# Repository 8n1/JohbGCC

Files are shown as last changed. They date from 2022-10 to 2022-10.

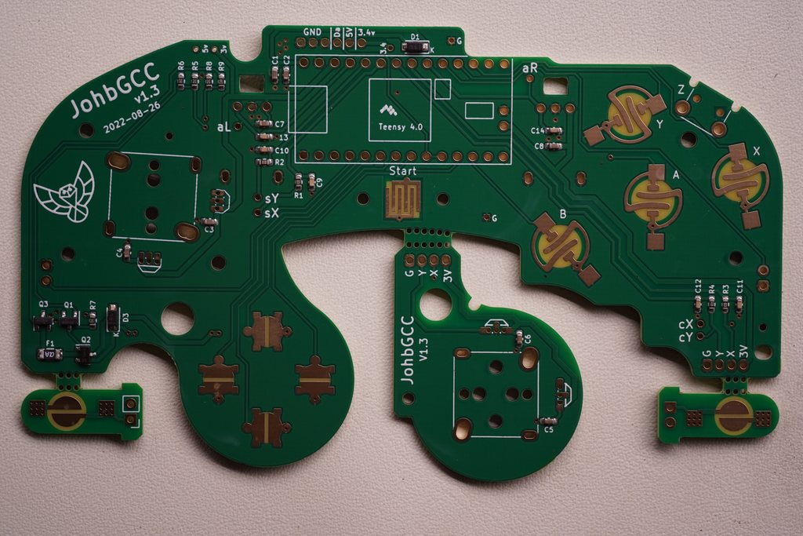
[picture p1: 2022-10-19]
Resources/johbgcc_board_top_v1_3.jpeg

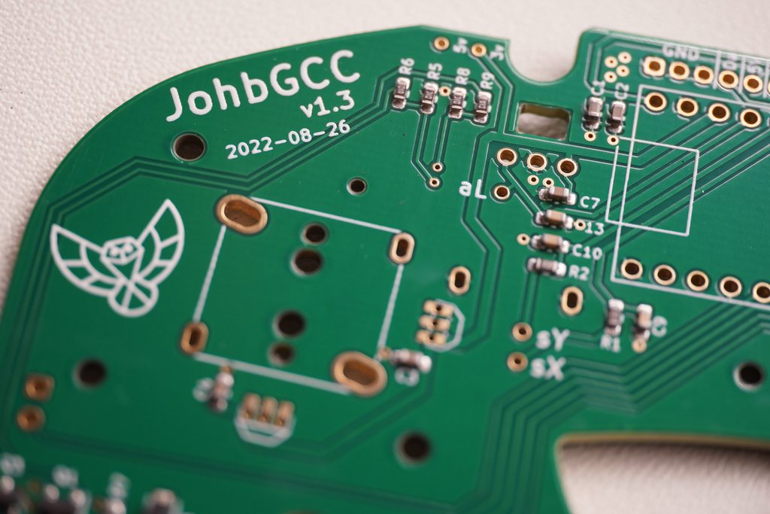
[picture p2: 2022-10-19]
Resources/johbgcc_board_v1_3.jpeg

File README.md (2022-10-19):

# JohbGCC v1.3


 
This board is based on the PhobGCC v1.2.3 board (https://github.com/PhobGCC/PhobGCC-HW).  
  
It is 100% compatible with the PhobGCC software but requires a custom teensy.h. (More info below).  

--- 
  
The Board was made with KiCad version 6.0.5.  
Gerber and assembly production files were created using the KiCad plugin "JLCPCB Tools"  (https://github.com/Bouni/kicad-jlcpcb-tools).  

# Changes

- **Rotated the stickbox into original position**  
- **Rotated the Teensy 180°**  
- **Optimized the board paneling for manufacturing**  
- **Added some labels to make it very fail proof and easier to build**  
- **Tried to make the board easier to desolder (More info below)**  

## Other changes 

- **Both hall sensors on the c stick have a decoupling capacitor now**  
- **Routed the 3.3V and filled the top layer with GND too**   

# PCB




# Schematic / PCB tracks

  
  
  
  

# Custom teensy.h
  
Before uploading the PhobGCC software to the Teensy you need to copy the teensy.h for this board ("Johb1_3Teensy4_0.h") into the "teensy" folder that comes with the Phob software and tell it to use it.   
  
The *teensy.h"* is the configuration file that tells the Phob software to what pins the buttons, triggers, hall sensors are connected to the Teensy.  
  
This board requires a custom one because I re-routed most of the board after rotating the Teensy and to keep tracks nice and short I switched the GPIO pins.  

## Adding the JohbGCC teensy.h 

**Step by step:**
1.  Download the PhobGCC software (https://github.com/PhobGCC/PhobGCC-SW/releases)
2.  Download the JohbGCC teensy.h (https://github.com/8n1/JohbGCC/blob/master/Johb1_3Teensy4_0.h) and put it into the "teensy" folder that is included in the PhobGCC software zip file.
3.  Edit the file "common/phobGCC.h" to use the added JohbGCC teensy.h by adding this line as shown in the picture below:  
```
#include "../teensy/Johb1_3Teensy4_0.h"             // For JohbGCC board 1.3.x with Teensy 4.0
```


4.  Done. Upload it to the Teensy. 

This has been tested with PhobGCC software v0.27 (https://github.com/PhobGCC/PhobGCC-SW/releases/tag/v0.27).  
For earlier versions the steps were slightly different.  
   
This is the only thing necessary to use the JohbGCC board with the PhobGCC software.  

# Modified/cut rumble bracket

It is necessary to modify the rumble bracket because the pins of the hall sensor interfere with it.  
  
**THIS MUST BE DONE, otherwise the controller can't be closed without force which causes various issues because the hall sensor pins will get crushed.**  
    
   
  
The text I put there says that it would be also possible to make the hall sensor pins flat instead but I found it much easier to just cut out a small part of the rumble bracket like shown in the pictures below so I would always recommend doing that.   
   
**"L" rumble bracket:**  
  
**Rumble bracket with integrated trigger guards:**  
  
More pictures before and after cutting:  
https://imgur.com/a/gytP62m  

# Making it easier to desolder

I wanted to make the holes for some parts like the L/R potentiometer and GCC cable not through hole plated to make it easier to desolder (as it is on a OEM GCC board) but I haven't looked into how to do this enough and misunderstood a option in KiCad ("connected layers only") so I didn't got exactly what I wanted:  
   
   
   
But that's not bad actually, part success!  
They are still through hole plated, what that option did was to only remove the solder ring on the side where it's not needed.

... 

After doing some research it looks like that KiCad doesn't has this exact option built in.   
But what you can do is take a smd pad and put a not trough hole plated hole (aka. mounting hole) in the middle of it. But this way this manufacturer specification limitation comes into play (this is from jlcpcb):  
   
  
(I want to try this out with the mounting pins of the potentiometers on the next board I make.)

# Pictures

**Hall sensor footprints on c stick**   
  
   
**Square indicators that show where the part/cable goes**   

  
**Labels that indicate hall sensor orientation**   


## More pictures

**Board as it came from JLCPCB:**  
https://imgur.com/a/ONnHoDy

**Soldered board:**  
https://imgur.com/a/rvYWUjU

***

# This project is based on PhobGCC
More informations about the PhobGCC project can be found here:  
https://github.com/PhobGCC  

***

# License
Text and images are licensed under Creative Commons CC-BY-SA.  
[Creative Commons Attribution-ShareAlike 4.0 International License](http://creativecommons.org/licenses/by-sa/4.0/ "Creative Commons Attribution-ShareAlike 4.0 International")  
  
  
KiCad board files are licensed under the CERN Open Hardware License.   
[CERN Open Hardware Licence Version 2 - Strongly Reciprocal](https://spdx.org/licenses/CERN-OHL-S-2.0.html "CERN Open Hardware Licence Version 2 - Strongly Reciprocal")  
Open source hardware logo  

***

If you have any questions contact me on discord (add me as a friend or find me in the PhobGCC discord): johgi#5103 (Might take a day or two to respond!)

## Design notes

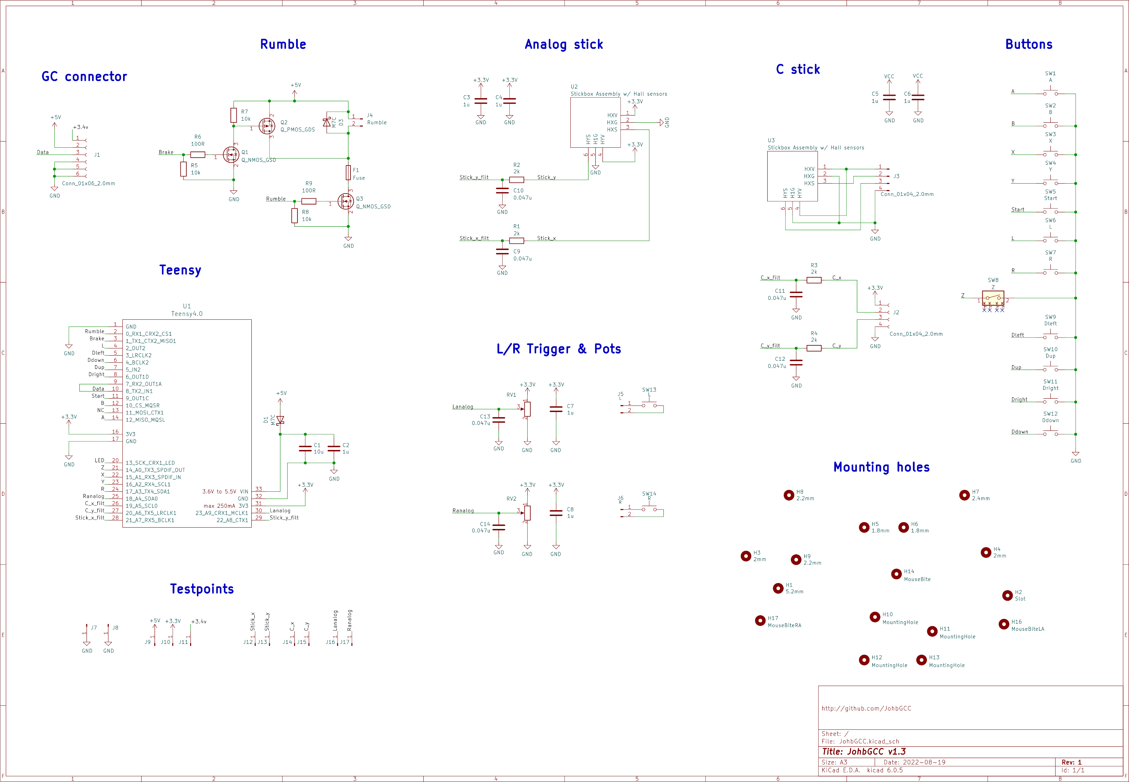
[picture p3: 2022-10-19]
Resources/johbgcc_schematic_v1_3.png

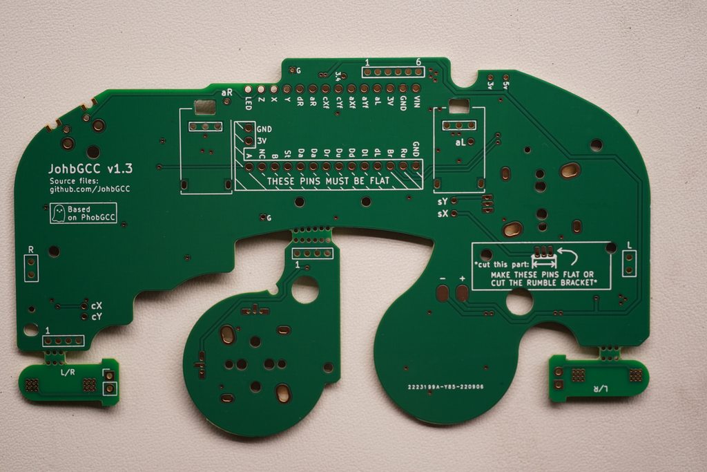
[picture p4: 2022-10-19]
Resources/johbgcc_board_bottom_v1_3.jpeg

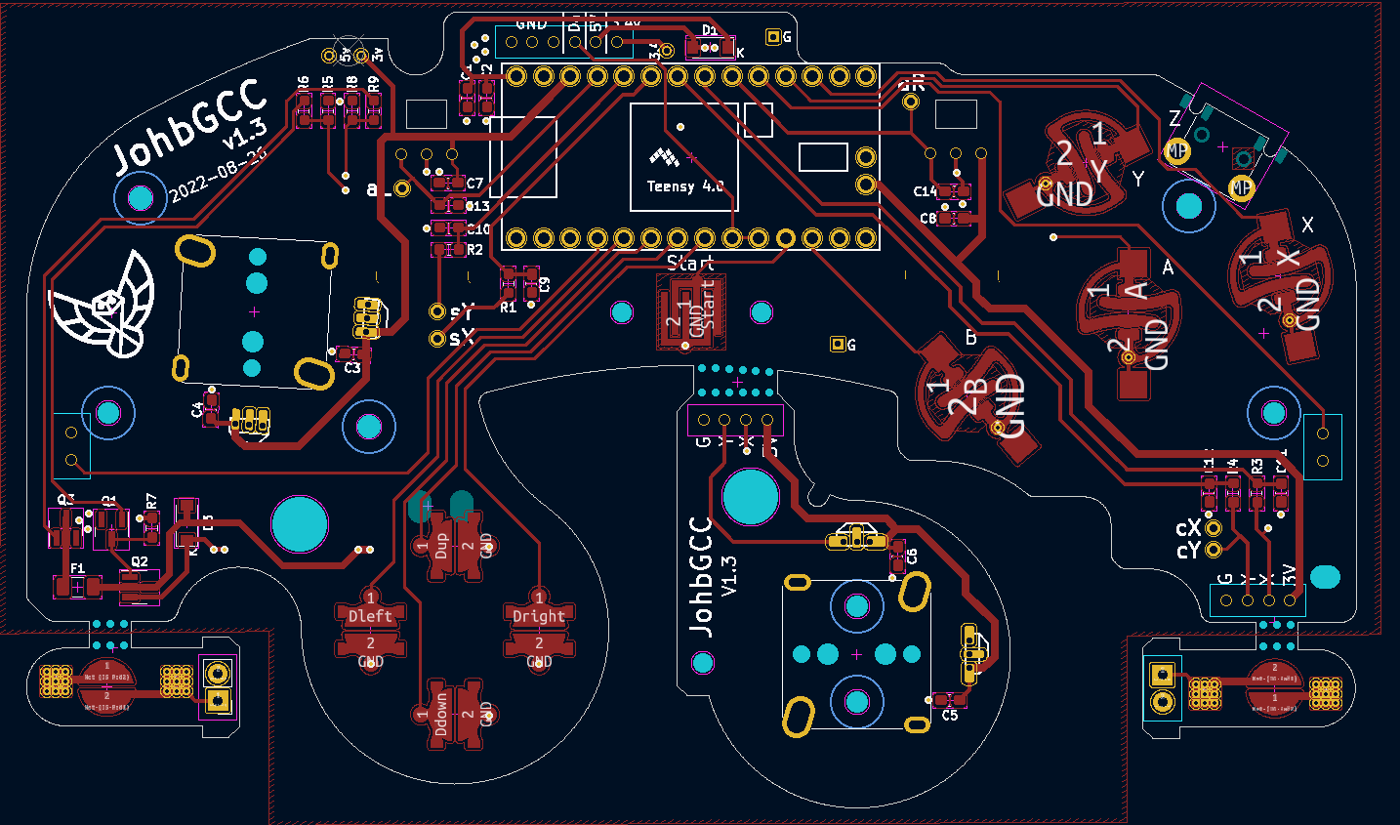
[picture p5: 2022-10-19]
Resources/johbgcc_pcb_tracks_top_v1_3.png

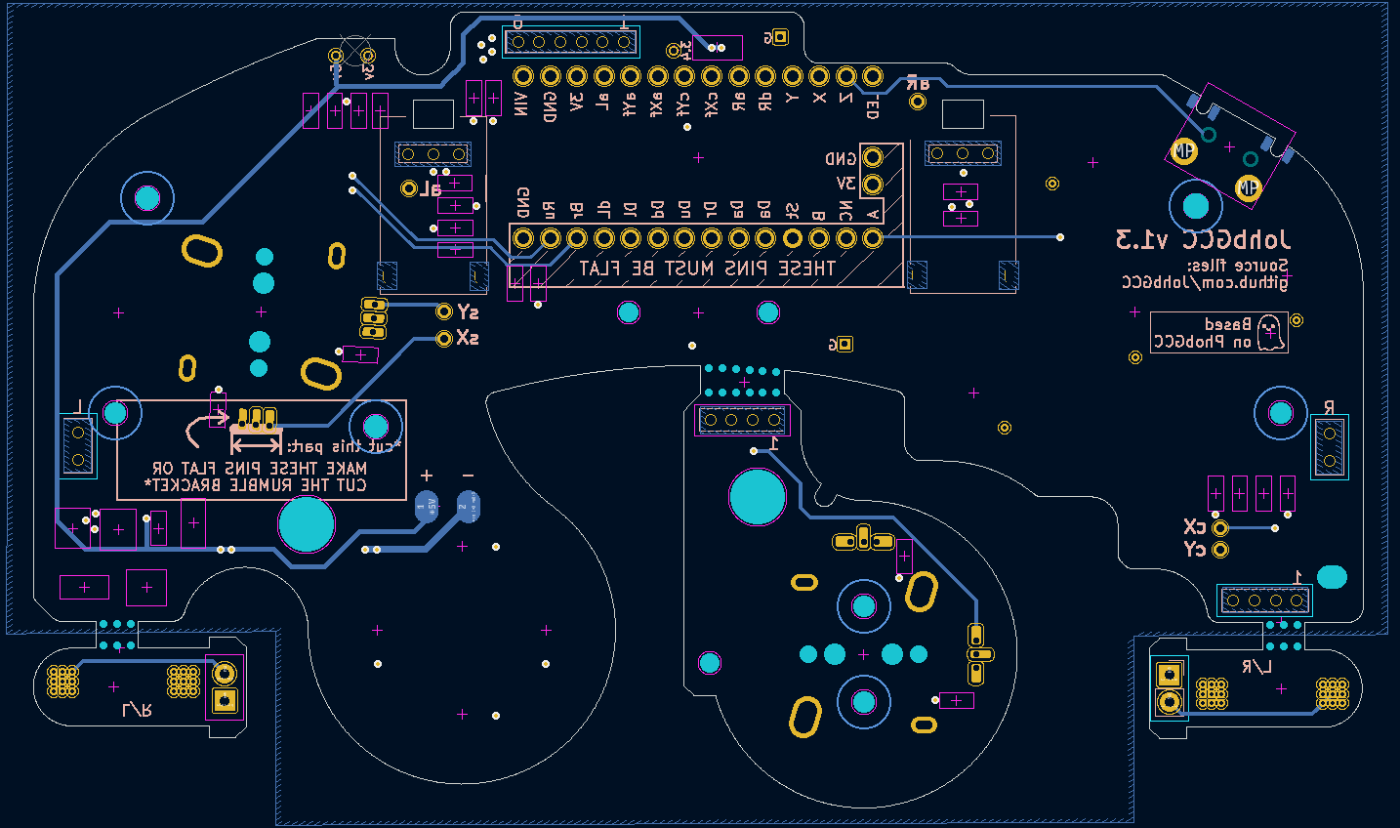
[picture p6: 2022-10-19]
Resources/johbgcc_pcb_tracks_bottom_v1_3.png

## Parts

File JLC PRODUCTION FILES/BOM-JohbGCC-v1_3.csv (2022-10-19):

Comment | Designator | Footprint | LCSC
1u | C2,C3,C4,C5,C6,C7,C8 | C_0603_1608Metric_Pad1.08x0.95mm_HandSolder | C15849
0.047u | C10,C11,C12,C13,C14,C9 | C_0603_1608Metric_Pad1.08x0.95mm_HandSolder | C1622
10u | C1 | C_0603_1608Metric_Pad1.08x0.95mm_HandSolder | C19702
100R | R6,R9 | R_0603_1608Metric_Pad0.98x0.95mm_HandSolder | C22775
2k | R1,R2,R3,R4 | R_0603_1608Metric_Pad0.98x0.95mm_HandSolder | C22975
10k | R5,R7,R8 | R_0603_1608Metric_Pad0.98x0.95mm_HandSolder | C25804
Q_PMOS_GDS | Q2 | SOT-23 | C15127
Q_NMOS_GSD | Q1,Q3 | SOT-23 | C20917
Fuse | F1 | Fuse_1206_3216Metric | C69680
M7C | D1,D3 | D_SOD-123 | C8598

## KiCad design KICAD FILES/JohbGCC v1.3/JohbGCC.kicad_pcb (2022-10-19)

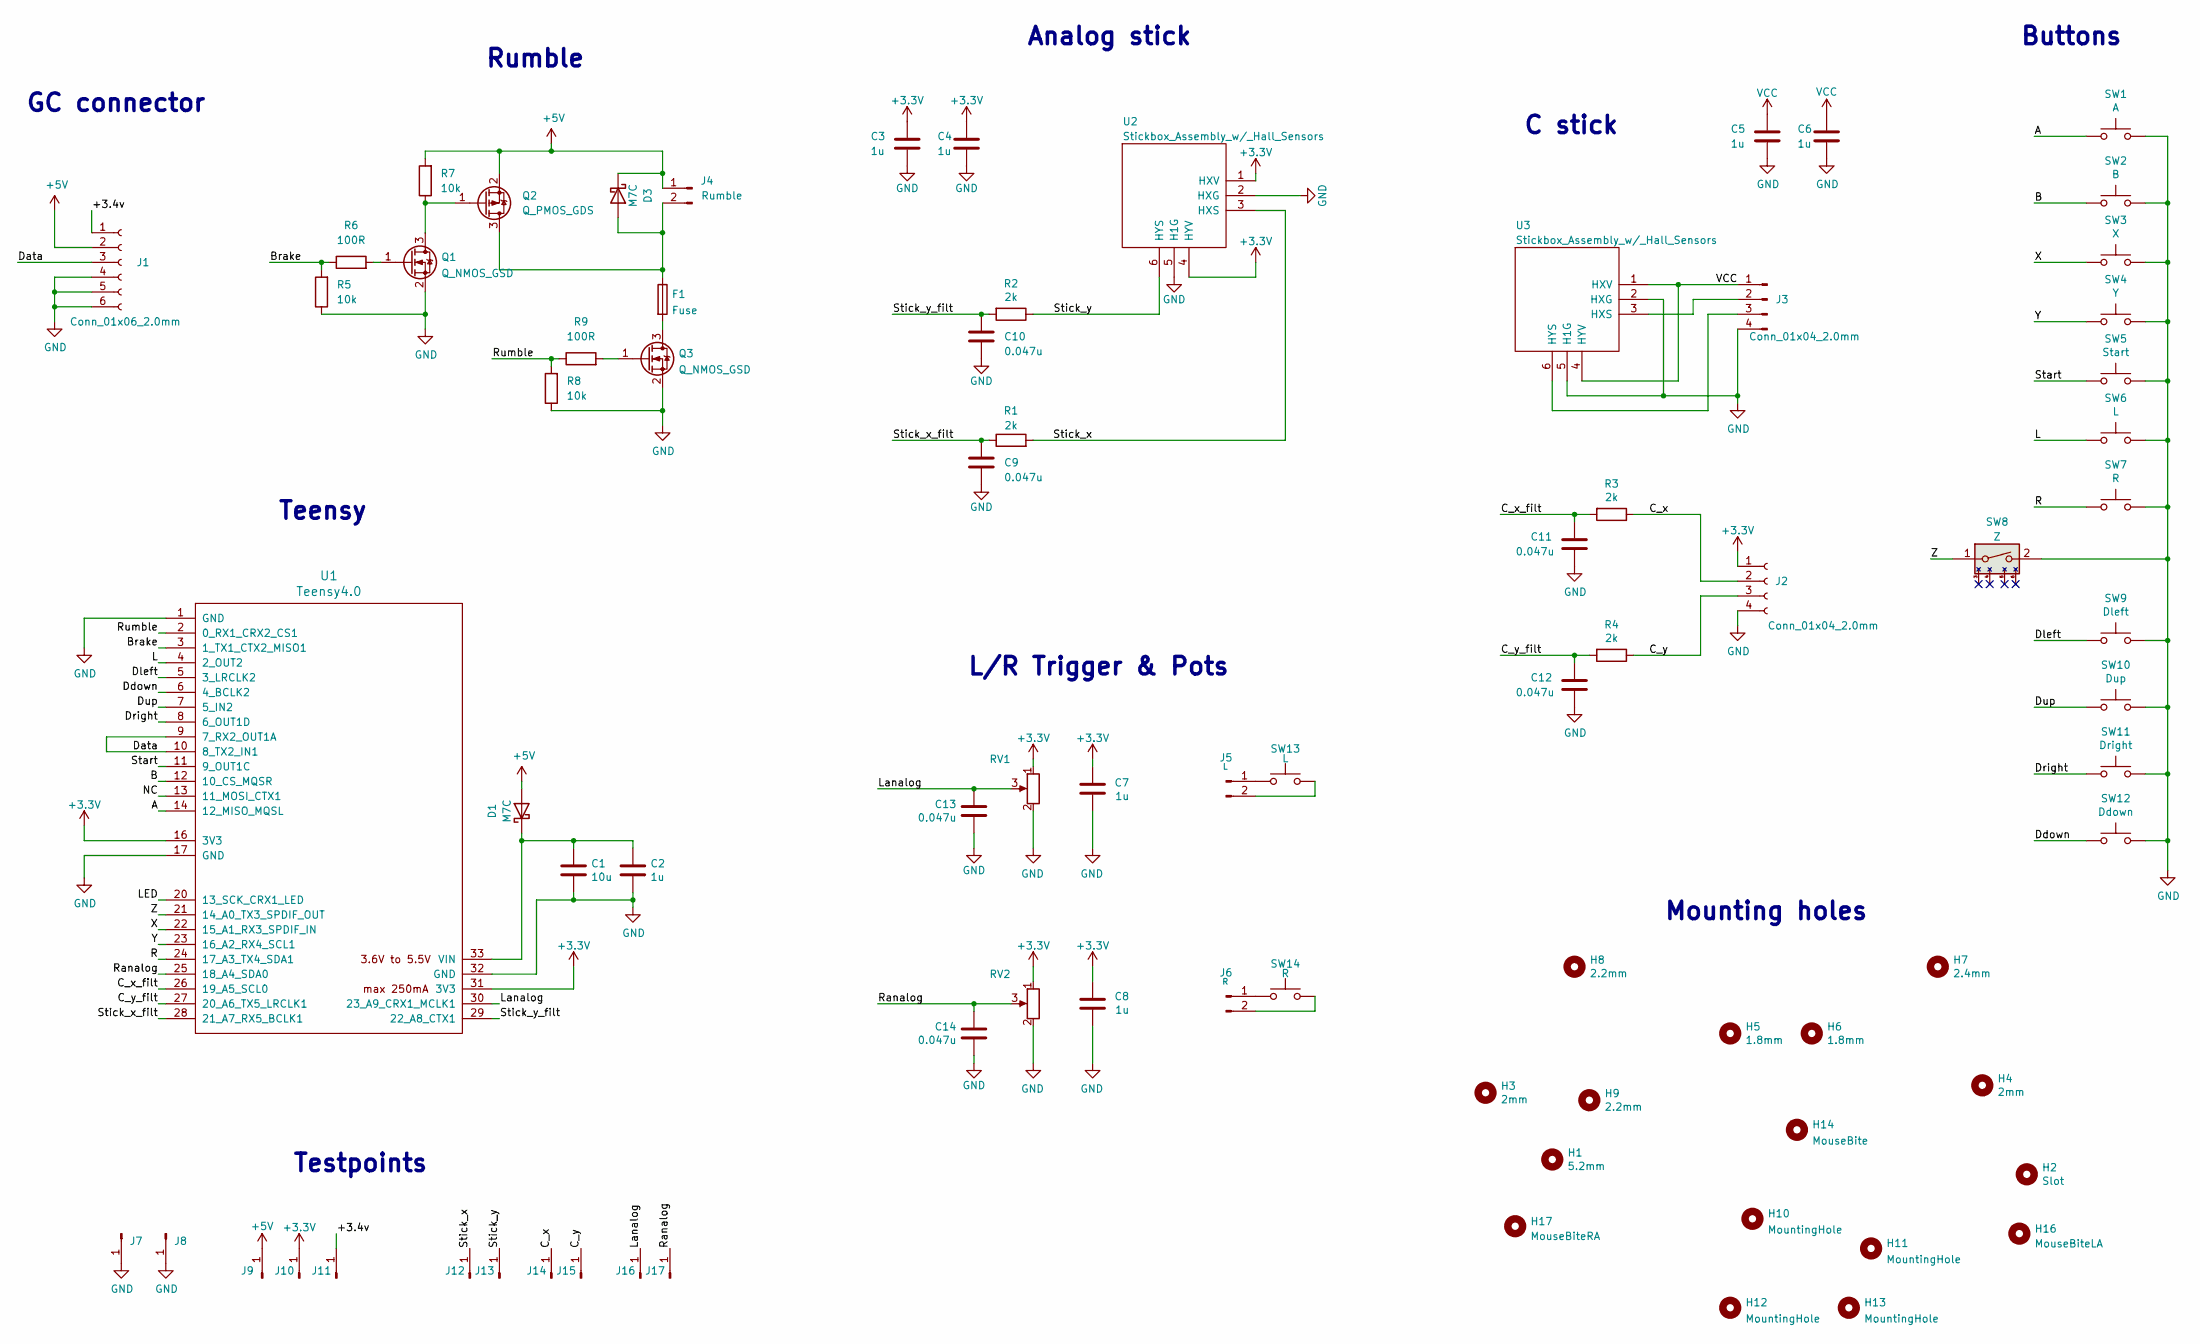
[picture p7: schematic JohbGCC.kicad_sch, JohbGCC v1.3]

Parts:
C1: 10u; C_0603_1608Metric_Pad1.08x0.95mm_HandSolder; LCSC C19702
C2, C3, C4, C5, C6, C7, C8: 1u; C_0603_1608Metric_Pad1.08x0.95mm_HandSolder; LCSC C15849
C9, C10, C11, C12, C13, C14: 0.047u; C_0603_1608Metric_Pad1.08x0.95mm_HandSolder; LCSC C1622
D1, D3: M7C; D_SOD-123; LCSC C8598
F1: Fuse; Fuse_1206_3216Metric; LCSC C69680
H1: 5.2mm; MountingHole_5.2mm
H2: Slot
H3, H4: 2mm; MountingHole_2.0mm
H5, H6: 1.8mm; MountingHole_1.8mm
H7: 2.4mm; MountingHole_2.4mm
H8, H9: 2.2mm; MountingHole_2.2mm
H10: MountingHole; MountingHole_1.8mm
H11: MountingHole; MountingHole_5.2mm
H12, H13: MountingHole; MountingHole_2.0mm
H14: MouseBite; JohbGCC_breakaway-mousebites-cstick
H16: MouseBiteLA; JohbGCC_breakaway-mousebites-lr
H17: MouseBiteRA; JohbGCC_breakaway-mousebites-lr
J1: Conn_01x06_2.0mm; GCC_Header_Straight_1x06_Pitch2.00mm
J2, J3: Conn_01x04_2.0mm; PinHeader_1x04_P2.00mm_Vertical
J4: Rumble; rumble_pins
J5: L; Pin_Header_Straight_1x02_Pitch2.54mm
J6: R; Pin_Header_Straight_1x02_Pitch2.54mm
J7, J8, J9, J10, J11, J12, J13, J14, J15, J16, J17: Conn_01x01_Male; PinHeader_1x01_P2.54mm_Vertical
Q1, Q3: Q_NMOS_GSD; SOT-23; LCSC C20917
Q2: Q_PMOS_GDS; SOT-23; LCSC C15127
R1: 2k; R_0603_1608Metric_Pad0.98x0.95mm_HandSolder; Manufacturer PN 0603WAF1002T5ECopy; LCSC C22975
R2, R3, R4: 2k; R_0603_1608Metric_Pad0.98x0.95mm_HandSolder; LCSC C22975
R5, R7, R8: 10k; R_0603_1608Metric_Pad0.98x0.95mm_HandSolder; LCSC C25804
R6, R9: 100R; R_0603_1608Metric_Pad0.98x0.95mm_HandSolder; LCSC C22775
RV1, RV2: R_POT_MountingPin; GCC_Slider
SW1: A; ABXY_Contact_Omron_Switch
SW2: B; ABXY_Contact_Omron_Switch
SW3: X; ABXY_Contact_Omron_Switch
SW4: Y; ABXY_Contact_Omron_Switch
SW5: Start; Start_Contact
SW6: L; Pin_Header_Straight_1x02_Pitch2.54mm
SW7: R; Pin_Header_Straight_1x02_Pitch2.54mm
SW8: Z; Z_Switch_Edge_Omron
SW9: Dleft; Dpad_Contact_TL3315NF_2
SW10: Dup; Dpad_Contact_TL3315NF_2
SW11: Dright; Dpad_Contact_TL3315NF_2
SW12: Ddown; Dpad_Contact_TL3315NF_2
SW13: L; Trigger_Contact
SW14: R; Trigger_Contact
U1: Teensy4.0; Teensy40_Edge_Pins
U2: Stickbox_Assembly_w/_Hall_Sensors; JohbGCC_Stickbox_w_Hall_Sensors_A_Stick
U3: Stickbox_Assembly_w/_Hall_Sensors; JohbGCC_Stickbox_w_Hall_Sensors_C_Stick

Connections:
+3.3V: C3.1, C4.1, C7.1, C8.1, J2.1, J10.1, RV1.1 (V+), RV2.1 (V+), U1.16 (3V3), U1.31 (3V3), U2.1 (HXV), U2.4 (HYV)
+5V: D1.2 (A), D3.1 (K), J1.2, J4.1, J9.1, Q2.2 (S), R7.2
/+3.4v: J1.1, J11.1
/A: SW1.1, U1.14 (12_MISO_MQSL)
/B: SW2.1, U1.12 (10_CS_MQSR)
/Brake: R5.2, R6.1, U1.3 (1_TX1_CTX2_MISO1)
/C_x: J2.2, J14.1, R3.1
/C_x_filt: C11.1, R3.2, U1.26 (19_A5_SCL0)
/C_y: J2.3, J15.1, R4.1
/C_y_filt: C12.1, R4.2, U1.27 (20_A6_TX5_LRCLK1)
/Data: J1.3, U1.9 (7_RX2_OUT1A), U1.10 (8_TX2_IN1)
/Ddown: SW12.1, U1.6 (4_BCLK2)
/Dleft: SW9.1, U1.5 (3_LRCLK2)
/Dright: SW11.1, U1.8 (6_OUT1D)
/Dup: SW10.1, U1.7 (5_IN2)
/L: SW6.1, U1.4 (2_OUT2)
/LED: U1.20 (13_SCK_CRX1_LED)
/Lanalog: C13.1, J16.1, RV1.3 (Signal), U1.30 (23_A9_CRX1_MCLK1)
/NC: U1.13 (11_MOSI_CTX1)
/R: SW7.1, U1.24 (17_A3_TX4_SDA1)
/Ranalog: C14.1, J17.1, RV2.3 (Signal), U1.25 (18_A4_SDA0)
/Rumble: R8.2, R9.1, U1.2 (0_RX1_CRX2_CS1)
/Start: SW5.1, U1.11 (9_OUT1C)
/Stick_x: J12.1, R1.2, U2.3 (HXS)
/Stick_x_filt: C9.1, R1.1, U1.28 (21_A7_RX5_BCLK1)
/Stick_y: J13.1, R2.1, U2.6 (HYS)
/Stick_y_filt: C10.1, R2.2, U1.29 (22_A8_CTX1)
/X: SW3.1, U1.22 (15_A1_RX3_SPDIF_IN)
/Y: SW4.1, U1.23 (16_A2_RX4_SCL1)
/Z: SW8.1, U1.21 (14_A0_TX3_SPDIF_OUT)
GND: C1.2, C2.2, C3.2, C4.2, C5.2, C6.2, C7.2, C8.2, C9.2, C10.2, C11.2, C12.2, C13.2, C14.2, J1.4, J1.5, J1.6, J2.4, J3.4, J7.1, J8.1, Q1.2 (S), Q3.2 (S), R5.1, R8.1, RV1.2 (GND), RV2.2 (GND), SW1.2, SW2.2, SW3.2, SW4.2, SW5.2, SW6.2, SW7.2, SW8.2, SW9.2, SW10.2, SW11.2, SW12.2, U1.1 (GND), U1.17 (GND), U1.32 (GND), U2.2 (HXG), U2.5 (H1G), U3.2 (HXG), U3.5 (H1G)
unnamed: C1.1, C2.1, D1.1 (K), U1.33 (VIN)
unnamed: D3.2 (A), F1.1, J4.2, Q2.3 (D)
unnamed: F1.2, Q3.3 (D)
unnamed: J3.2, U3.3 (HXS)
unnamed: J3.3, U3.6 (HYS)
unnamed: J5.1, SW13.2
unnamed: J5.2, SW13.1
unnamed: J6.1, SW14.2
unnamed: J6.2, SW14.1
unnamed: Q1.1 (G), R6.2
unnamed: Q1.3 (D), Q2.1 (G), R7.1
unnamed: Q3.1 (G), R9.2
VCC: C5.1, C6.1, J3.1, U3.1 (HXV), U3.4 (HYV)

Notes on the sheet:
Buttons
Rumble
C stick
Analog stick
Testpoints
L/R Trigger & Pots
GC connector
Teensy
Mounting holes

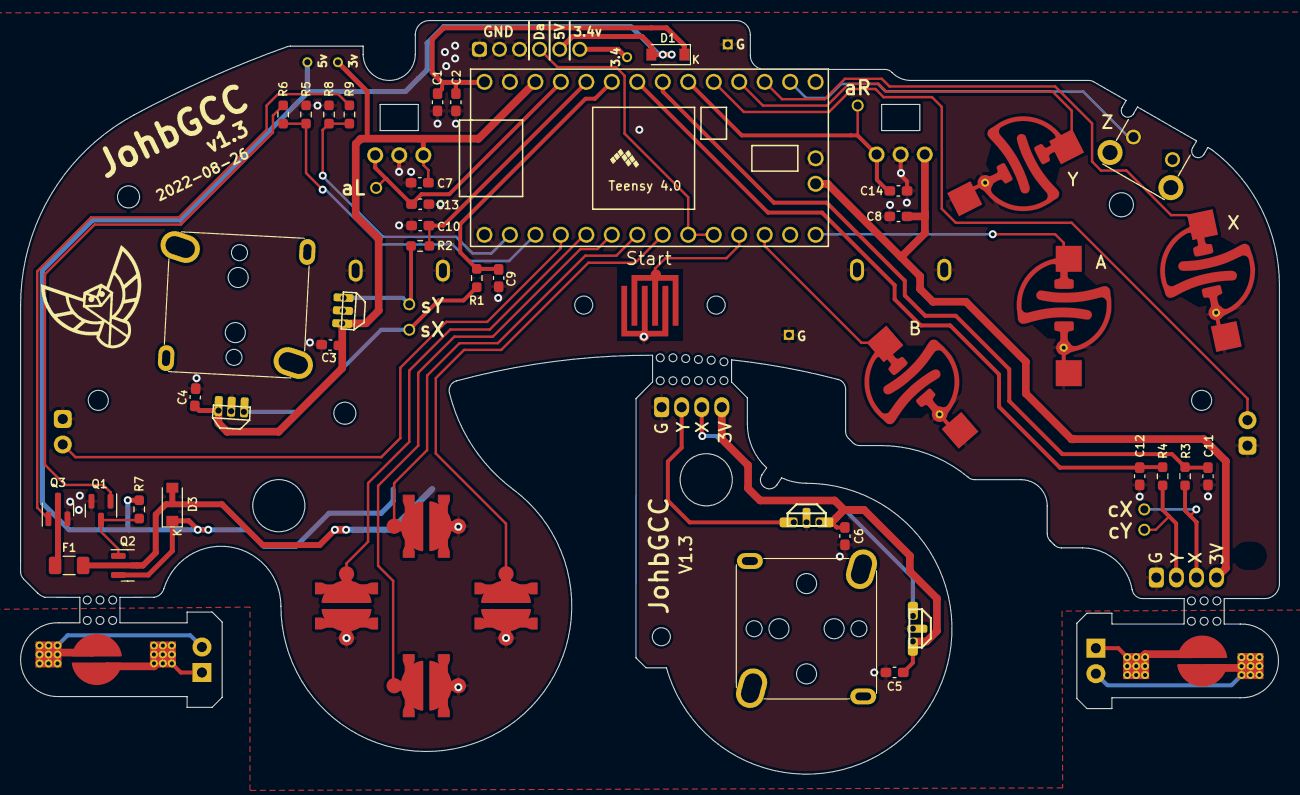
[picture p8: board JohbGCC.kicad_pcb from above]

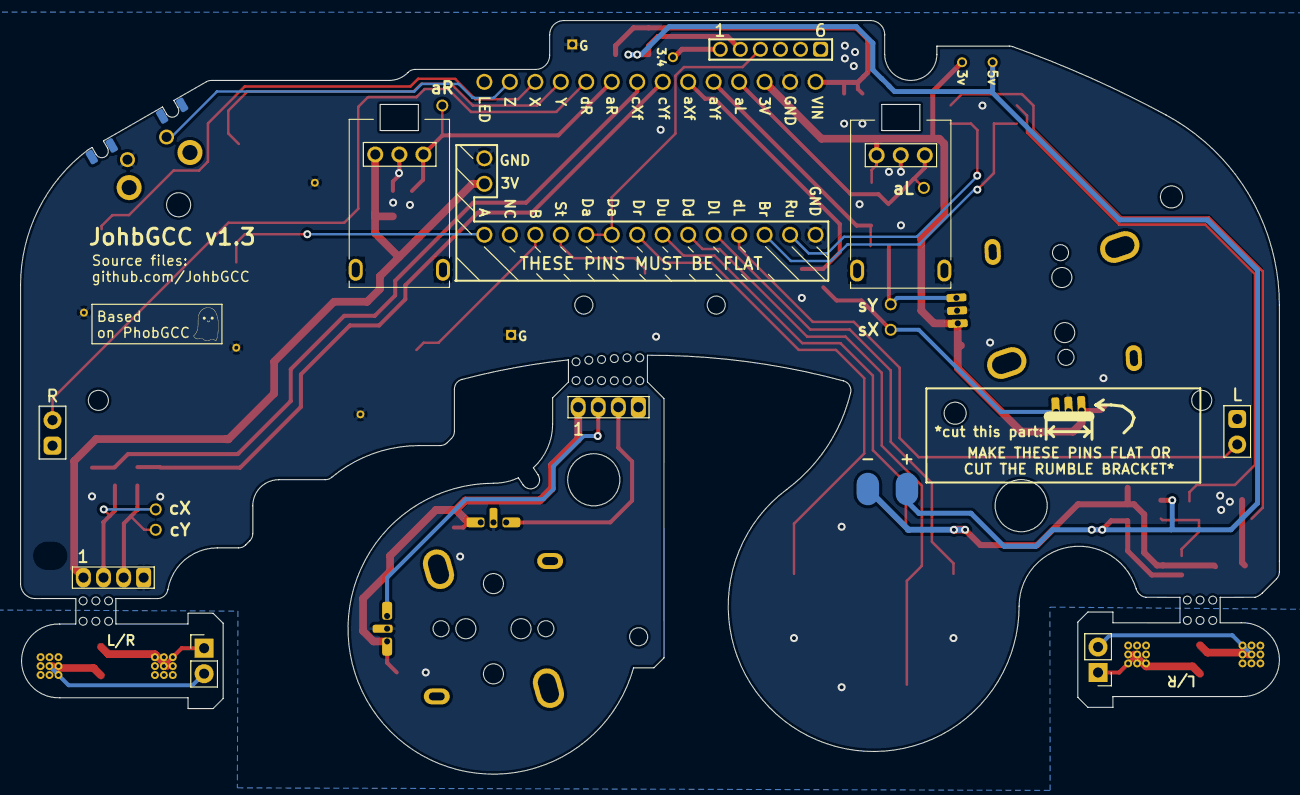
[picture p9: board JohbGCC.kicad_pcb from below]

Board: 2 copper layers, 125.5 x 75.1 mm, 81 parts (20 on the bottom side), 42 nets.

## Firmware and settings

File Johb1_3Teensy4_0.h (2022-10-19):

#ifndef BOARD_H
#define BOARD_H

#include <ADC.h>
#include <VREF.h>
#include "settings.h"

//Hardware specific code for JohbGCC board revision 1.3 with a Teensy 4.0
#define TEENSY4_0
#define RUMBLE

//Hardware specific code for half duplex—using one pin for both TX and RX
#define HALFDUPLEX

//defining which pin is what on the teensy
const int _pinRX = 7;
const int _pinTX = 8;
const int _pinInt = 7;
const int _pinLED = 13;
const int _pinLa = 23;
const int _pinRa = 18;
const int _pinL = 2;
const int _pinR = 17;
const int _pinAx = 22;
const int _pinAy = 21;
const int _pinCx = 19;
const int _pinCy = 20;
const int _pinDr = 6;
const int _pinDu = 5;
const int _pinDl = 3;
const int _pinDd = 4;
const int _pinX = 15;
const int _pinY = 16;
const int _pinA = 12;
const int _pinB = 10;
const int _pinZ = 14;
const int _pinS = 9;
const int _pinRumble = 0;
const int _pinBrake = 1;

//don't #define USEADCSCALE

void serialSetup() {
    Serial.begin(115200);
    Serial.println("This is the header for JohbGCC board revision 1.3 with a Teensy 4.0.");
}

void ADCSetup(ADC * adc,
              float &,/*ADCScale not used*/
              float & /*ADCScaleFactor not used*/) {
    adc->adc0->setAveraging(1);
    adc->adc0->setResolution(12);
    adc->adc0->setConversionSpeed(ADC_CONVERSION_SPEED::HIGH_SPEED);
    adc->adc0->setSamplingSpeed(ADC_SAMPLING_SPEED::VERY_HIGH_SPEED);

}

//must include at the end
#include "readHardware.h"
#include "comms.h"
#endif // BOARD_H

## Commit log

2022-10-19 initial upload
    [BOM-JohbGCC-v1_3.csv, JohbGCC.kicad_pcb, JohbGCC.kicad_sch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]
2022-10-19 fixed link to the johb teensy.h
